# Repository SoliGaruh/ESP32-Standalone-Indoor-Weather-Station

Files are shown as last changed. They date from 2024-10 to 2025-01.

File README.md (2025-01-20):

# ESP32-Standalone-Indoor-Weather-Station

A weather station that includes:

ESP32 devkit or similar 30 pin device;
DFRobot 1602 LCD display;
Adafruit BME280 module that provides temperature, humidity and air pressure;
A momentary on pushbutton.

It was developed using MS Visual Studio Code and PlatformIO.

The device uses a WiFi Manager to connect to a user selectable WiFi AP for the sole purpose of synchronising the time using NTP. This allows the device to display the minimum and maximum values for each sensor for the current day. The device will operate without a WiFi connection but the min and max values will be since the device was powered on. They can only be cleared by cycling the power.

The following libraries are required:

DFRobot_RBGLCD1602
tzapu/WiFiManager@^2.0.17
arduinogetstarted/ezButton@^1.0.4
adafruit/Adafruit BME280 Library@^2.2.4
adafruit/Adafruit Unified Sensor @ ^1.1.14

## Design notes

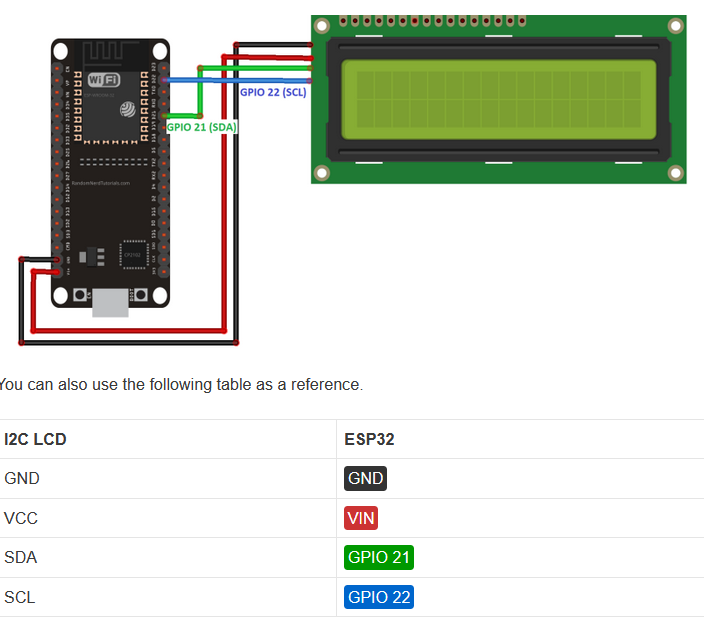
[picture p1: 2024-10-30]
ESP32 2x16 LCD Display.png

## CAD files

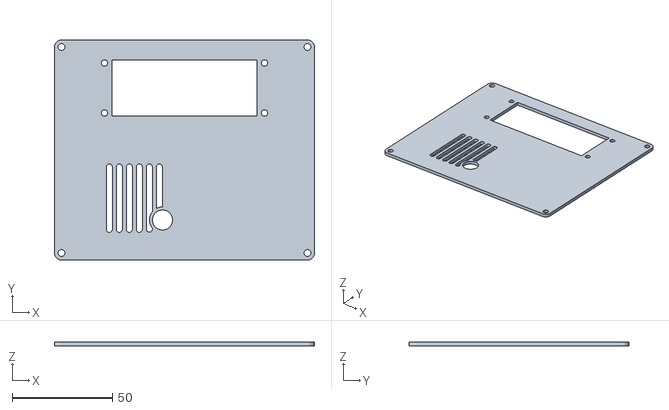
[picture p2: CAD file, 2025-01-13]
SIWS Top.stl
130.0 x 110.0 x 2.00

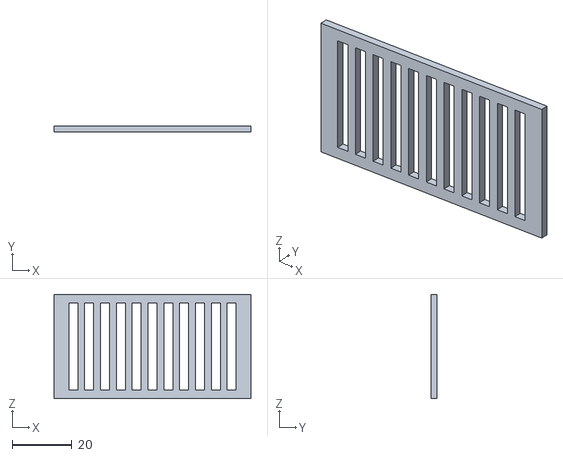
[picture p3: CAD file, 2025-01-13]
Ventilation Insert.stl
66.0 x 2.00 x 35.0

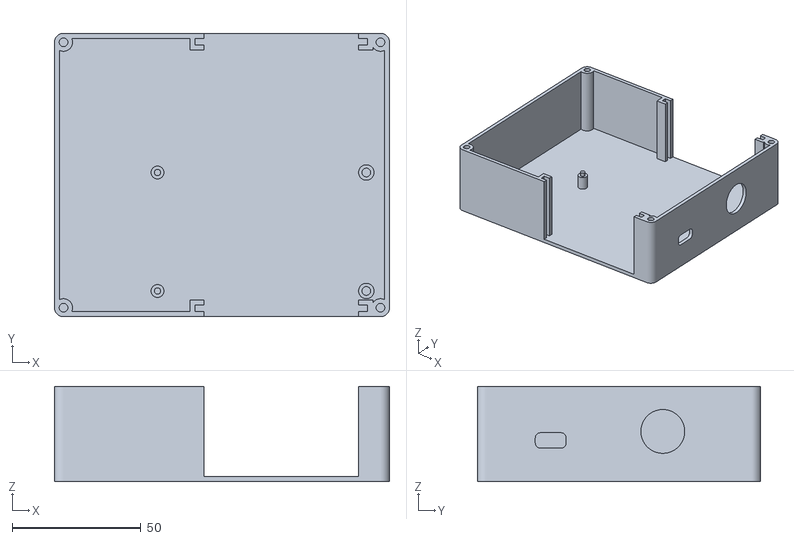
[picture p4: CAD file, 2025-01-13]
SIWS Base.stl
130.0 x 110.0 x 37.0

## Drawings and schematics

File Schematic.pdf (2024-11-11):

VCC | GND

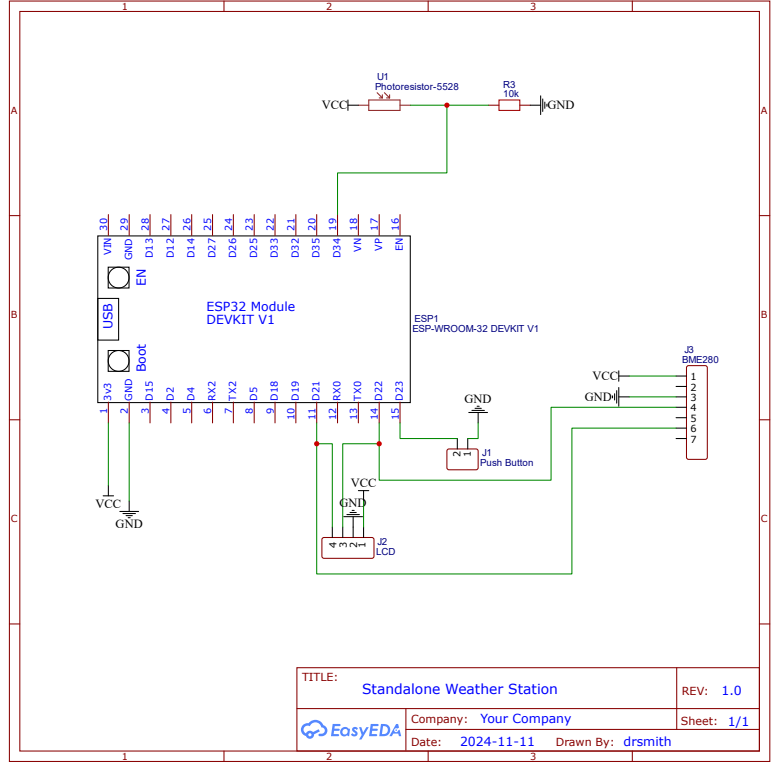
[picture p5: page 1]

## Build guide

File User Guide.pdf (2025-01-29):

### Standalone Indoor Weather Station User Guide

## Overview

The Standalone Indoor Weather Station (SIWS) contains three environmental sensors; temperature, air pressure and humidity. Each of these sensors is updated once per minute and can be displayed on the inbuilt LCD display.

The SIWS also contains a light sensor. The LCD display will automatically dim in dull light but will still be readable.

## The Display

The SIWS features a two row LCD display shown below.

Temperature readings are displayed by default when the device is powered on.

The top row shows:
1. the most recent temperature reading, in this example it is 26.4 degrees Celsius. All temperature values are show in Celsius; and
2. the time when the most recent temperature reading was observed. In this example it was at 11:40. Note that the time is presented in 24hr format.

The bottom row shows:
1. the lowest temperature observed today (24.4); and
2. the highest temperature observed today (26.4).

The daily low and high observations are reset everyday at midnight.

The time will be displayed as XX:XX if the Wi-Fi has not been configured (see below). The SIWS will still operate and record sensor observations without the time having been initialised, but the low and high values will never be reset.

Quickly pushing and releasing the push button on the right hand side will cycle between each of the sensors alternating between temperature, air pressure and humidity.

The layout of the display is the same for each sensor type. The layout for the air pressure and humidity displays are shown below.

v1.1

Figure 1: Temperature Display

Air pressure is displayed in hectopascals.

Humidity is displayed as a percentage.

## Wi-Fi Setup

The SIWS indicates when the Wi-Fi and hence the time has not been set by displaying XX:XX in place of the time in the top right corner of the display.

The current time can be obtained from the Internet via Wi-Fi. The entered Wi-Fi credentials are retained so they only need to be setup once or when the SIWS is moved to a new location that uses different Wi-Fi credentials.

The SIWS will briefly connect to the internet via Wi-Fi every time it is switched on. Once the current time has been obtained, the SIWS disconnects from the Wi-Fi completely.

To setup the Wi-Fi you will need:
1. a Wi-Fi network with internet access, typically a home Wi-Fi router;
2. a mobile phone or tablet device on which to enter the Wi-Fi credentials.

## Step 1 – Place the SIWS into Wi-Fi setup mode

To place the device into Wi-Fi setup mode, hold the push button down for at least two seconds and then release it.

Figure 2: Air Pressure Display

Figure 3: Humidity Display

The display will show it is in Wi-Fi setup mode. The device will be in this mode for five minutes, but don’t worry, you can always place it into this mode again if you run out of time.

Placing the device into Wi-Fi setup mode will erase any previously stored Wi-Fi credentials.

## Step 2 – Select the Wi-Fi Network from your Phone or Tablet

Using your mobile phone or tablet open the Settings app and go to the Wi-Fi settings. On my Android phone, it looks like this:

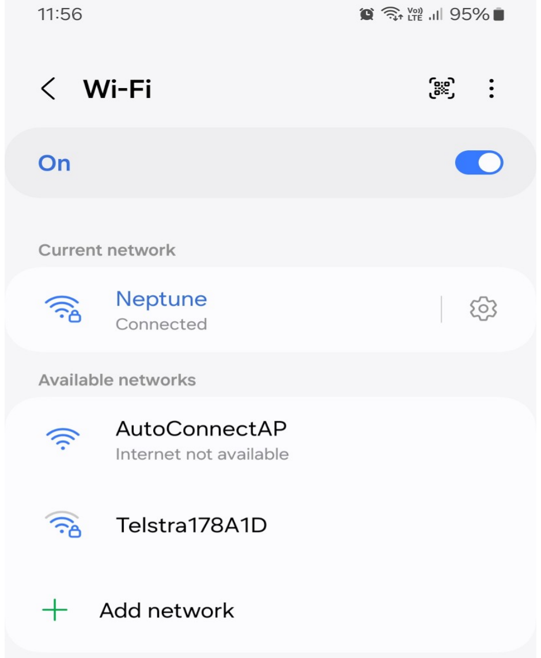
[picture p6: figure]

Configure your phone/tablet to connect to the Wi-Fi network called ‘AutoConnectAP’. Doing this will connect the phone/tablet to the Wi-Fi network being provided by the SIWS. This is just used to enter your Wi-Fi credentials and does need internet access. No password is required.

Think of it like you are using your phone/tablet as a keyboard and monitor for the SIWS.

Figure 4: Wi-Fi Setup Mode

Note: I have found that it is best to wait for the phone/tablet to ask you to confirm that you really want to use this network even though it doesn’t provide any internet access. Just say yes, use it this one time.

## Step 3 – Enter the Wi-Fi Credentials

Open a browser on your phone/tablet and enter IP address “192.168.4.1” into the address/search field as shown below. You should see the following screen.

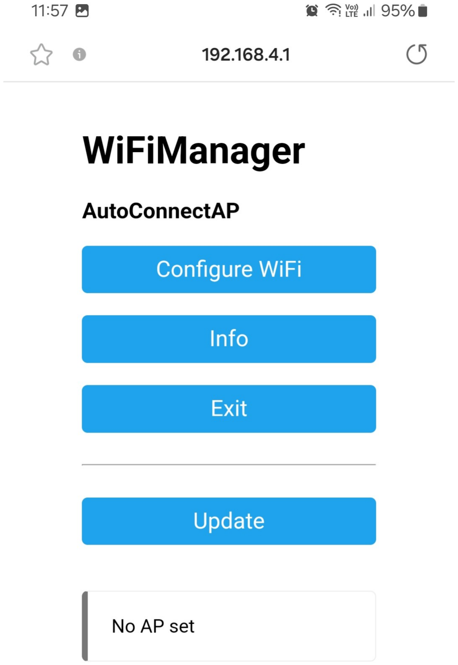
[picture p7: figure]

Tap on the “Configure WiFi” button. A screen will be presented allowing you to enter the Wi-Fi credentials that the SIWS will use to access the time via the internet.

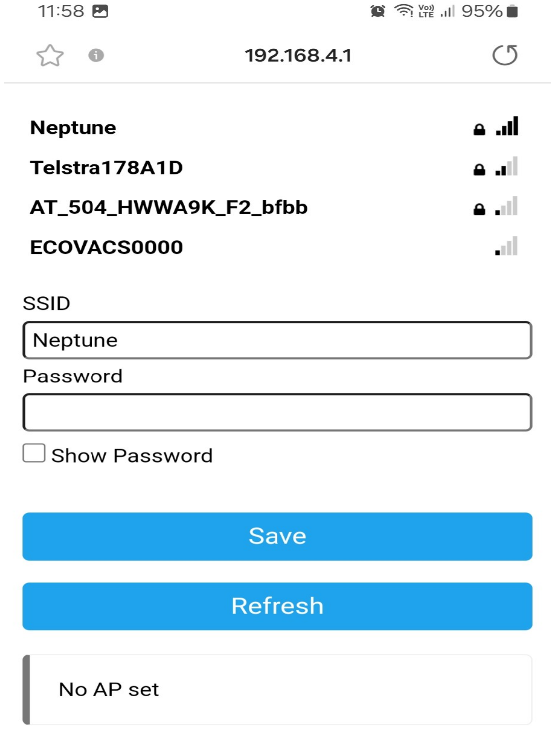
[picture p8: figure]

Tap on the name of the Wi-Fi network to use from the list at the top. In this case my home Wi-Fi network is called Neptune. Enter the Wi-Fi password and tap the “Save” button. The app will close.

Note that the Refresh button refreshes the list of detected Wi-Fi networks.

## Step 4 – Magic Happens

So now, the SIWS will connect to the Internet using the entered Wi-Fi credentials and obtain the time. It will now display the time in place of XX:XX.

Your phone/tablet will revert to the Wi-Fi settings it had before.

## Deleting the Time

If you don’t care about the time and you would rather just see the time as XX:XX you can delete the Wi-Fi credentials and hence the time.
To do this, hold down the push button for at least two seconds to place the SIWS in Wi-Fi setup mode.
Now, turn the SIWS off and back on again.

## Known Limitations

Due to some limitations in the software, the time zone is hard-coded to South Australia. If you take the SIWS to somewhere else in the world, it will still work, but will show the time in SA time. An initial version of the software allowed the user to enter the time zone alongside the Wi-Fi credentials, but the ability to obtain the current time from the internet didn’t work reliably. It
seemed confused whether daylight saving was in effect or not.

It is currently unclear what happens when daylight savings starts or ends. The software knows about daylight savings but you might need to turn the SIWS off and on to reset the clock inline with daylight saving changes in SA. I don’t know, I can’t really test that.

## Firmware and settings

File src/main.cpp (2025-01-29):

#include <Arduino.h>
#include <WiFiManager.h> // https://github.com/tzapu/WiFiManager
#include <WiFi.h>
#include <time.h>
#include <FS.h>
#include <ezButton.h>
#include <Wire.h>
#include <SPI.h>
#include <Adafruit_Sensor.h>
#include <Adafruit_BME280.h>

#include "DFRobot_RGBLCD1602.h"
#include "sensor.h"

#if CONFIG_FREERTOS_UNICORE
static const BaseType_t app_cpu = 0;
#else
static const BaseType_t app_cpu = 1;
#endif

// The pin the button is wired to
#define BUTTON_PIN 23

// Define the pin for the photoresistor. Note that ADC2 pins cannot be used when WiFi is being used.
// This is because the WiFi driver uses ADC2 pins. The photoresistor is connected to an ADC1 pin.
#define photoResistorPin 34

// How many ms equates to a long button press
#define LONG_PRESS_MS 2000

#define BME_SCK 22
#define BME_MISO 12
#define BME_MOSI 21
#define BME_CS 10

#define SEALEVELPRESSURE_HPA (1013.25)

Adafruit_BME280 bme; // I2C sensor

// Create a mutex handle to ensure the LCD is not accessed by multiple tasks at the same time
SemaphoreHandle_t xLCDMutex;

// LCD display is 16 characters and 2 lines. RGB address 0x60 is for LCD1602 v1.0
// LCD display is 16 characters and 2 lines. RGB address 0x6B is for LCD1602 v1.1
DFRobot_RGBLCD1602 lcd(0x6B, 16, 2);

ezButton button(BUTTON_PIN); // create ezButton object that attaches to pin BUTTON_PIN;

// which sensor board is being used
int currentBoard = 0;

// Structure used to receive sensor data and to pass the data to the loop task via a RTOS queue
typedef struct message_t
{
    bool tIsValid;
    float temperature;

    bool pIsValid;
    unsigned pressure;

    bool hIsValid;
    unsigned humidity;

    unsigned readingId;
} message_t;

enum status : char
{
    ok = 0,
    failed
};

// RTOS queue settings

// Size of msg_queue. Needs to be large enough to hold all messages.
// Entering WiFi credentials can cause a message a minute to be generated during the 5 minute timeout.
const int msg_queue_len = 10;
QueueHandle_t msg_queue;

// what to display on the LCD. Default to Temperature
enum displayMode : char
{
    TemperatureMode = 0,
    PressureMode,
    HumidityMode
};
displayMode currentDisplayMode = TemperatureMode;

Sensor<float> temperatureSensor;
Sensor<unsigned> pressureSensor;
Sensor<unsigned> humiditySensor;

status getWiFiStatus()
{
    if (WiFi.status() == WL_CONNECTED)
    {
        return ok;
    }
    else
    {
        return failed;
    }
}

void timeSync(const char *tzInfo, const char *ntpServer1, const char *ntpServer2)
{
    // Accurate time is necessary for certificate validion

    configTzTime(tzInfo, ntpServer1, ntpServer2);

    // Wait till time is synced
    Serial.print("Syncing time");
    int i = 0;
    while (time(nullptr) < 1000000000l && i < 40)
    {
        Serial.print(".");
        delay(500);
        i++;
    }
    Serial.println();

    // Show time
    time_t tnow = time(nullptr);
    Serial.print("Synchronized time: ");
    Serial.println(ctime(&tnow));
}

void setupWiFi(int timeoutSeconds, bool resetSettings = false)
{
    WiFi.mode(WIFI_STA); // explicitly set mode, esp defaults to STA+AP

    // WiFiManager, Local initialization. Once its business is done, there is no need to keep it around
    WiFiManager wm;

    if (resetSettings)
    {
        wm.resetSettings();
    }

    // Automatically connect using saved credentials,
    // if connection fails, it starts an access point with the specified name ("AutoConnectAP"),
    // if empty will auto generate SSID, if password is blank it will be anonymous AP (wm.autoConnect())
    // then goes into a blocking loop awaiting configuration and will return success result
    //
    // The device still works if the WiFi is disconnected, but the time will not be updated

    bool res;

    wm.setTimeout(timeoutSeconds);         // Set timeout in seconds
    res = wm.autoConnect("AutoConnectAP"); // anonymous ap

    if (!res)
    {
        Serial.println("Failed to connect");
    }
    else
    {
        Serial.println("Connected to WiFi");
    }
}

void adjustBacklight(void *parameter)
{
    int photoValue;
    int pwm;

    while (1)
    {
        // Read the value from the photo resistor. the value will be between 0 and 4095. the higher the value, the brighter the light
        photoValue = analogRead(photoResistorPin);

        Serial.print("Photo Resistor Value: ");
        Serial.println(photoValue); // Print the value to the serial monitor

        pwm = map(photoValue, 0, 2000, 125, 255);
        if (pwm > 255)
        {
            pwm = 255;
        }

        // Protect access to the LCD with the mutex
        if (xSemaphoreTake(xLCDMutex, portMAX_DELAY) == pdTRUE)
        {
            // Set the backlight intensity to the mapped value
            lcd.setPWM(lcd.REG_ONLY, pwm);

            // Release the mutex
            xSemaphoreGive(xLCDMutex);
        }
        vTaskDelay(5000 / portTICK_PERIOD_MS);
    }
}

void readSensors(void *parameter)
{
    message_t msg;
    unsigned readingId = 0;

    while (1)
    {
        // Read the sensors
        msg.temperature = bme.readTemperature();
        msg.tIsValid = (msg.temperature != NAN);

        msg.pressure = static_cast<unsigned>(bme.readPressure() / 100.0F);
        msg.pIsValid = (msg.pressure != 0);

        msg.humidity = static_cast<unsigned>(bme.readHumidity());
        msg.hIsValid = (msg.humidity != 0);

        msg.readingId = readingId++;

        xQueueSend(msg_queue, (void *)&msg, 10 / portTICK_PERIOD_MS);

        // The sensors are read once per minute
        vTaskDelay(60000 / portTICK_PERIOD_MS);
    }
}

void DisplayTemperature(Sensor<float> &ts)
{
    // Protect access to the LCD with the mutex
    if (xSemaphoreTake(xLCDMutex, portMAX_DELAY) == pdTRUE)
    {
        lcd.clear();
        lcd.printf("Temp:%3.1f", ts.GetValue());
        lcd.setCursor(11, 0);
        lcd.print(ts.GetTime().c_str());
        lcd.setCursor(0, 1);
        lcd.printf("L:%3.1f H:%3.1f",
                   ts.GetMin(),
                   ts.GetMax());

        // Release the mutex
        xSemaphoreGive(xLCDMutex);
    }
}

void DisplayPressure(Sensor<unsigned> &ps)
{
    // Protect access to the LCD with the mutex
    if (xSemaphoreTake(xLCDMutex, portMAX_DELAY) == pdTRUE)
    {
        lcd.clear();
        lcd.printf("Press:%4d", ps.GetValue());
        lcd.setCursor(11, 0);
        lcd.print(ps.GetTime().c_str());
        lcd.setCursor(0, 1);
        lcd.printf("L:%4d H:%4d",
                   ps.GetMin(),
                   ps.GetMax());

        // Release the mutex
        xSemaphoreGive(xLCDMutex);
    }
}

void DisplayHumidity(Sensor<unsigned> &hs)
{
    // Protect access to the LCD with the mutex
    if (xSemaphoreTake(xLCDMutex, portMAX_DELAY) == pdTRUE)
    {
        lcd.clear();
        lcd.printf("Hum:%2d", hs.GetValue());
        lcd.setCursor(11, 0);
        lcd.print(hs.GetTime().c_str());
        lcd.setCursor(0, 1);
        lcd.printf("L:%2d H:%2d",
                   hs.GetMin(),
                   hs.GetMax());

        // Release the mutex
        xSemaphoreGive(xLCDMutex);
    }
}

void setup()
{
    // Initialize Serial Monitor
    Serial.begin(115200);
    vTaskDelay(2000 / portTICK_PERIOD_MS);

    pinMode(photoResistorPin, INPUT); // Set the photo resistor pin as an input
    pinMode(BUTTON_PIN, INPUT_PULLUP);
    button.setDebounceTime(50); // set debounce time to 50 milliseconds

    bool status = bme.begin();
    if (!status)
    {
        Serial.println("Could not find a valid BME280 sensor, check wiring, address, sensor ID!");
        Serial.print("SensorID was: 0x");
        Serial.println(bme.sensorID(), 16);
        Serial.print("        ID of 0xFF probably means a bad address, a BMP 180 or BMP 085\n");
        Serial.print("   ID of 0x56-0x58 represents a BMP 280,\n");
        Serial.print("        ID of 0x60 represents a BME 280.\n");
        Serial.print("        ID of 0x61 represents a BME 680.\n");
    }

    // Create the mutex for LCD access
    xLCDMutex = xSemaphoreCreateMutex();

    // initialize the LCD. Don't need to protect this with the mutex as it is only called once. There are
    // no other tasks running at this point.
    lcd.init();
    lcd.print("Initialising...");

    // setup the wifi but using a short timeout and don't reset AP values. That way, the WiFi will connect
    // if it has been connected before. The user must long press to reset the WiFi credentials.
    setupWiFi(5);

    if (WiFi.status() == WL_CONNECTED)
    {
        timeSync("ACST-9:30ACDT,M10.1.0,M4.1.0/3", "pool.ntp.org", "time.nis.gov");
    }

    // disconnect the WiFi as it is no longer needed. Only used to grab the time. Turn off the WiFi radio as well to generate
    // less heat.

    WiFi.disconnect(true);
    WiFi.mode(WIFI_OFF);

    // Create the message queue used to pass sensor data to the main loop
    msg_queue = xQueueCreate(msg_queue_len, sizeof(message_t));

    // Define the task that will read the sensors
    xTaskCreatePinnedToCore(
        readSensors,    // Function that should be called
        "Read Sensors", // Name of the task (for debugging)
        4096,           // Stack size (bytes)
        NULL,           // Parameter to pass
        1,              // Task priority
        NULL,           // Task handle
        app_cpu);       // which core to use

    // Define the task that will adjust the backlight
    xTaskCreatePinnedToCore(
        adjustBacklight,    // Function that should be called
        "Adjust Backlight", // Name of the task (for debugging)
        2048,               // Stack size (bytes)
        NULL,               // Parameter to pass
        1,                  // Task priority
        NULL,               // Task handle
        app_cpu);           // which core to use
}

void loop()
{
    static unsigned long buttonPressedTime;

    // Is there any sensor data on the queue?
    message_t incomingReadings;
    if (xQueueReceive(msg_queue, (void *)&incomingReadings, 0) == pdTRUE)
    {
        if (incomingReadings.tIsValid)
        {
            Serial.printf("Temperature: %3.1f\n", incomingReadings.temperature);
            temperatureSensor.SetValue(incomingReadings.temperature, "Builtin");
        }
        else
        {
            Serial.println("Temperature reading is invalid");
        }

        if (incomingReadings.pIsValid)
        {
            Serial.printf("Pressure: %d\n", incomingReadings.pressure);
            pressureSensor.SetValue(incomingReadings.pressure, "Builtin");
        }
        else
        {
            Serial.println("Pressure reading is invalid");
        }

        if (incomingReadings.hIsValid)
        {
            Serial.printf("Humidity: %d\n", incomingReadings.humidity);
            humiditySensor.SetValue(incomingReadings.humidity, "Builtin");
        }
        else
        {
            Serial.println("Humidity reading is invalid");
        }

        Serial.printf("Reading ID: %d\n\n", incomingReadings.readingId);

        // refresh the display.
        if (currentDisplayMode == TemperatureMode)
        {
            DisplayTemperature(temperatureSensor);
        }
        else if (currentDisplayMode == PressureMode)
        {
            DisplayPressure(pressureSensor);
        }
        else if (currentDisplayMode == HumidityMode)
        {
            DisplayHumidity(humiditySensor);
        }
    }

    // check the pushbutton
    // MUST call the loop() function first, the library requires it.
    button.loop();

    if (button.isPressed())
    {
        Serial.println("The button is pressed");
        buttonPressedTime = millis();
    }

    if (button.isReleased())
    {
        Serial.println("The button is released");
        if (millis() - buttonPressedTime > LONG_PRESS_MS)
        {
            // long press signifies the user wants to enter wifi credentials
            Serial.println("Long press");

            // Protect access to the LCD with the mutex
            if (xSemaphoreTake(xLCDMutex, portMAX_DELAY) == pdTRUE)
            {
                lcd.clear();
                lcd.print("Setup WiFi...");

                // Release the mutex
                xSemaphoreGive(xLCDMutex);
            }

            // setup the wifi
            setupWiFi(300, true); // timeout is 5 minutes and AP values are cleared

            if (WiFi.status() == WL_CONNECTED)
            {
                timeSync("ACST-9:30ACDT,M10.1.0,M4.1.0/3", "pool.ntp.org", "time.nis.gov");
            }

            // disconnect the WiFi as it is no longer needed. Only used to grab the time. Turn off the WiFi radio as well to generate
            // less heat.
            WiFi.disconnect(true);
            WiFi.mode(WIFI_OFF);
        }
        else
        {
            // short press signifies the user wants to change mode, ie, from Temperature to Pressure
            Serial.println("Short press");

            // this will cycle through the enum values. Note that HumidityMode MUST be the last
            // value defined in the displayMode enumerated type for this to work.
            currentDisplayMode = (enum displayMode)((currentDisplayMode + 1) % (HumidityMode + 1));
        }
        // refresh the display.
        if (currentDisplayMode == TemperatureMode)
        {
            DisplayTemperature(temperatureSensor);
        }
        else if (currentDisplayMode == PressureMode)
        {
            DisplayPressure(pressureSensor);
        }
        else if (currentDisplayMode == HumidityMode)
        {
            DisplayHumidity(humiditySensor);
        }
    }
    vTaskDelay(100 / portTICK_PERIOD_MS);
}

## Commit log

2024-11-11 RC3 includes photo resistor
2024-11-11 Added schematic
2024-12-26 Fixed min/max values when date is not set
    [main.cpp]
2025-01-07 added case picture
2025-01-13 added STL case files
    [SIWS Base v3.stl, SIWS Top No Fillet.stl, Ventilation Insert.stl]
2025-01-20 Added user guide and tidy up docs
    [SIWS Base.stl, SIWS Top.stl]
